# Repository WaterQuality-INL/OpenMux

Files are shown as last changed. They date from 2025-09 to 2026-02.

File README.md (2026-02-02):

# OpenMux Overview
OpenMux is an extension of the research conducted within the framework of the [OPTIRAS project](https://www.optiras.org/), particularly from the [Water Quality Group](https://inl.int/espina-research-group/) at the [International Iberian Nanotechnology Laboratory](https://inl.int/).
We aim to provide an open-source multiplexer adaptor for the [EmStat4 LR/HR potentiostat](https://www.palmsens.com/product/emstat4m/) by combining hardware design with software integration. This innovation enhances experimental efficiency and scalability for researchers and engineers at an exceptionally low cost, paving the way for applications such as multiplexed electrochemical sensing, automated assay platforms, and integrated IoT-based field monitoring systems for environmental, biomedical, or industrial electrochemical analysis.

The use of OpenMux is demonstrated in the article ["Multiplexed potentiometric sensing of nitrite in environmental waters"](https://doi.org/10.1016/j.aca.2026.345190) [1].

---

## About

This repository provides **OpenMux**, a homemade and cost-effective multiplexer adaptor for the EmStat4 OEM module from Palmsens. 
The adaptor is integrated with the potentiostat using the [**MethodScript**]([https://github.com/PalmSens](https://www.palmsens.com/methodscript/)) protocol provided by the manufacturer.

The system consists of two main modules:  

1. **Hardware Module** – the multiplexer adaptor (figure 1), whose schematics and PCB layout were developed using KiCad 7.0. Schematic, layout, and Gerber files can be found in the `Hardware/` folder (see [schematic.pdf](Hardware/schematic.pdf) and [layout.pdf](Hardware/layout.pdf) for pictures).  
2. **Graphical User Interface (GUI)** – a graphical user interface (figure 2) to control the adaptor, implemented in Python 3.8. The GUI is located in the `Application/`  folder.

<div align="center">
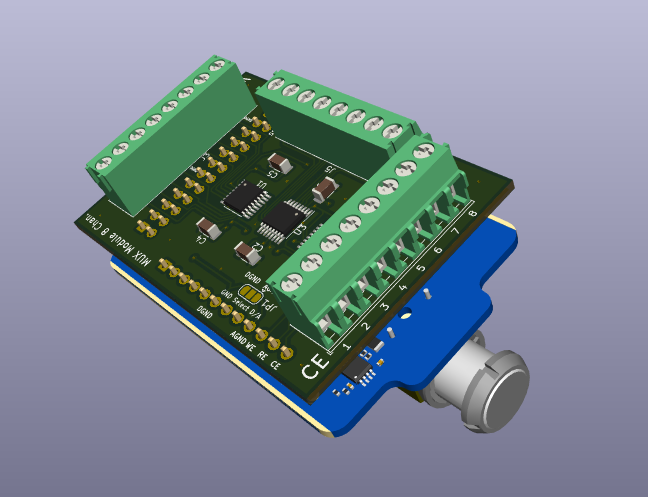
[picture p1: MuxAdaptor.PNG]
Multiplexer Adaptor for EmStat4
  
  <p><em>Figure 1: OpenMux adaptor for EmStat4</em></p>
</div>

<div align="center">
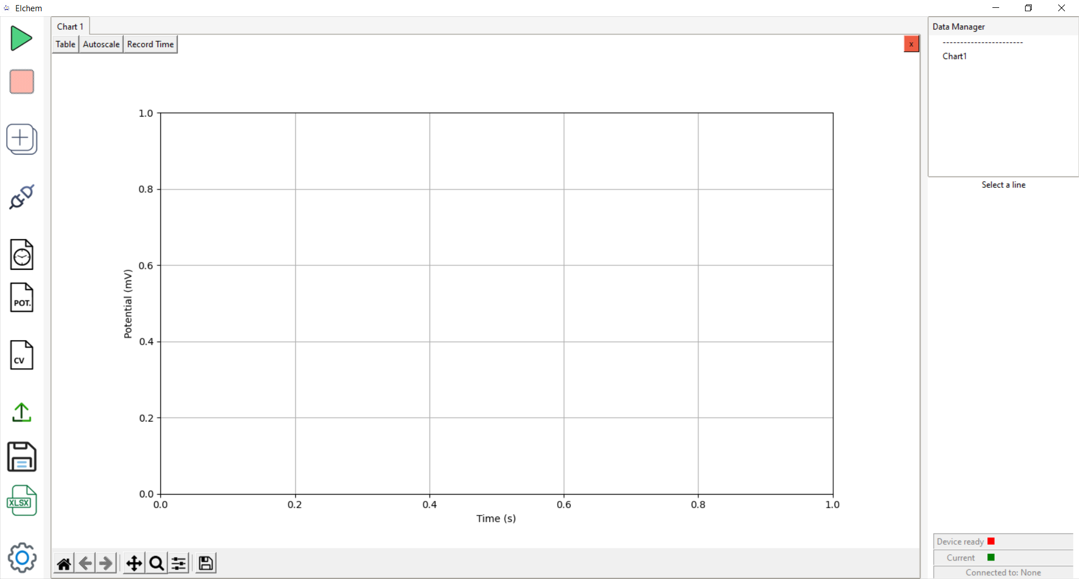
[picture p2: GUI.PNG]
Graphical User Interface
  
  <p><em>Figure 2: OpenMux GUI</em></p>
</div>

The application of OpenMux for electrochemical methods is described in the scientific literature [2].

## Who is this for?

- Electrochemists who want a cheap and modular, open platform for integrating sensors and data backends for:
   - Environmental or industrial monitoring applications
   - Scaling up sensor optimisation and/or preparation in the lab
  
---

## Costs

The approximate cost of the electronic components (excluding the PCB) is around **€40**. Key components include:

| Quantity | Component | Price | Link |
|---|---|---|---|
| 3x | ADG1408YRUZ Multiplexer | €10 | [Digi-Key](https://www.digikey.pt/en/products/detail/analog-devices-inc/ADG1408YRUZ/1206709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) |
| 3x | Phoenix Terminal Block 8-pos | €1.60 | [Digi-Key](https://www.digikey.pt/en/products/detail/phoenix-contact/1984675/950853) |
| 3x | Male Pin Header 12-pos | €0.14 | [Digi-Key](https://www.digikey.pt/en/products/detail/adam-tech/PH1-12-UA/9830395) |
| 3x | Female Pin Header 12-pos | €0.49 | [Digi-Key](https://www.digikey.pt/en/products/detail/w%C3%BCrth-elektronik/61301211821/16608531) |

---

## Getting Started

1) Clone or download the repository 
```bash
git clone https://github.com/WaterQuality-INL/OpenMux.git
cd OpenMux
```

2) Hardware and production
- Gerber files for production: `Hardware/production/Mux_Module.zip`
- Schematics and PCB: in `Hardware/` (KiCad 7.x)
- Fabricate the PCB (JLCPCB, PCBWay, etc.), order components, and assemble.

3) Software requirements
- Python 3.8 or newer (3.8–3.11 recommended)
- OS: Windows, Linux, or macOS (GUI tested on Windows; Linux/macOS supported)
- The Application uses `MethodScript-firmware/` and `Icons/` folders; these must be present when running the packaged executable (see Packaging below).

4) Run the GUI (development)

Windows (cmd / PowerShell)
```bash
cd Application
python -m venv venv
venv\Scripts\activate.bat    # PowerShell: venv\Scripts\Activate.ps1
pip install -r requirements.txt
python EL_MUX.py
```

Linux / macOS
```bash
cd Application
python3 -m venv venv
source venv/bin/activate
pip install -r requirements.txt
python3 EL_MUX.py
```

5) OPTIONAL: Packaging (creating an executable)

Alternatively, an executable file can also be created, allowing this application to run in computers where python is not installed.
```bash
cd Application
venv\Scripts\activate.bat
pyinstaller -w -p "venv\Lib\site-packages" -i Icons/group-30_116053.ico --onefile EL_MUX.py
```

Notes:
- The produced executable still depends on the folders `MethodScript-firmware/` and `Icons/`. Place `EL_MUX.exe` into `Application/` alongside those folders before running.
- After verifying the executable works, you can remove the `build/` and `dist/` directories.

---

## Troubleshooting

- If the GUI cannot find the EmStat4 device, verify the USB/serial connection and port name.
- Ensure the virtual environment is activated and dependencies installed.
- For packaging issues, build the executable on the target OS (pyinstaller builds are OS-specific).

---

## License

- Software (Application/) is licensed under the MIT License.  
- <p> Hardware (Hardware/) is licensed under <a href=https://creativecommons.org/licenses/by/4.0/> CC BY 4.0 </a>    </p>

---

## Contributors
- Samuel Silva*

Supervision:
- Álvaro Geraldes**

Contacts:
- Samuel Silva, samuel.silva@inl.int
- Álvaro Geraldes, alvaro.geraldes@inl.int

*Water Quality Group, **Systems Engineering Group, International Iberian Nanotechnology Laboratory (INL)

---

## Acknowledgement
To PalmSens for MethodScript

This work is an extension of the research project funded by EEA (European Economic Area) Grants Portugal through the funded project PT-INN-0076—OPTIRAS.

---

## References
[1] Renato L. Gil, Samuel Silva, Marília B. Santos, Álvaro Geraldes, Begoña Espiña, Raquel B. Queirós. Multiplexed potentiometric sensing of nitrite in environmental waters. Analytica Chimica Acta 2026, https://doi.org/10.1016/j.aca.2026.345190

[2] Olesia Dudik, Renato L. Gil, Raquel B. Queirós. Critical assessment of different ion-to-electron transducers in modified screen-printed electrodes for potentiometric lithium sensing. Microchemical Journal 2025, 215, 114195, https://doi.org/10.1016/j.microc.2025.114195

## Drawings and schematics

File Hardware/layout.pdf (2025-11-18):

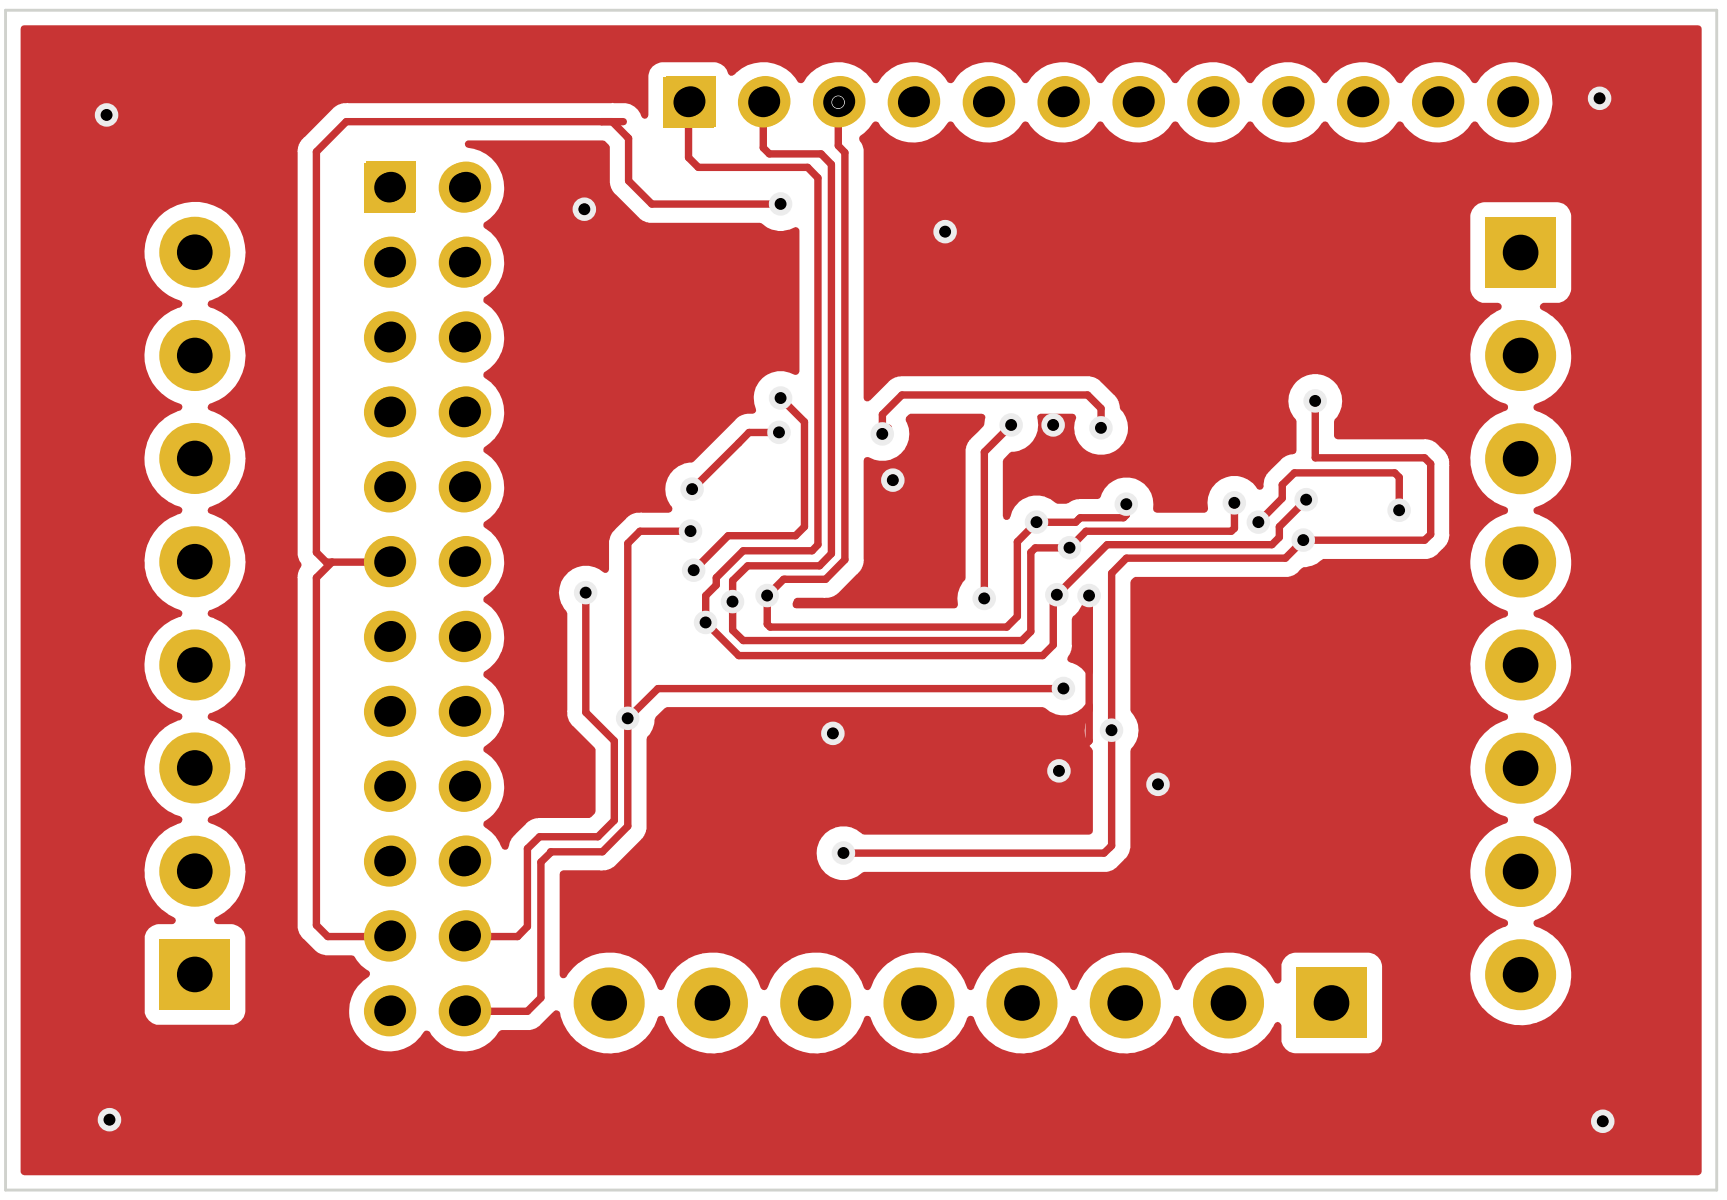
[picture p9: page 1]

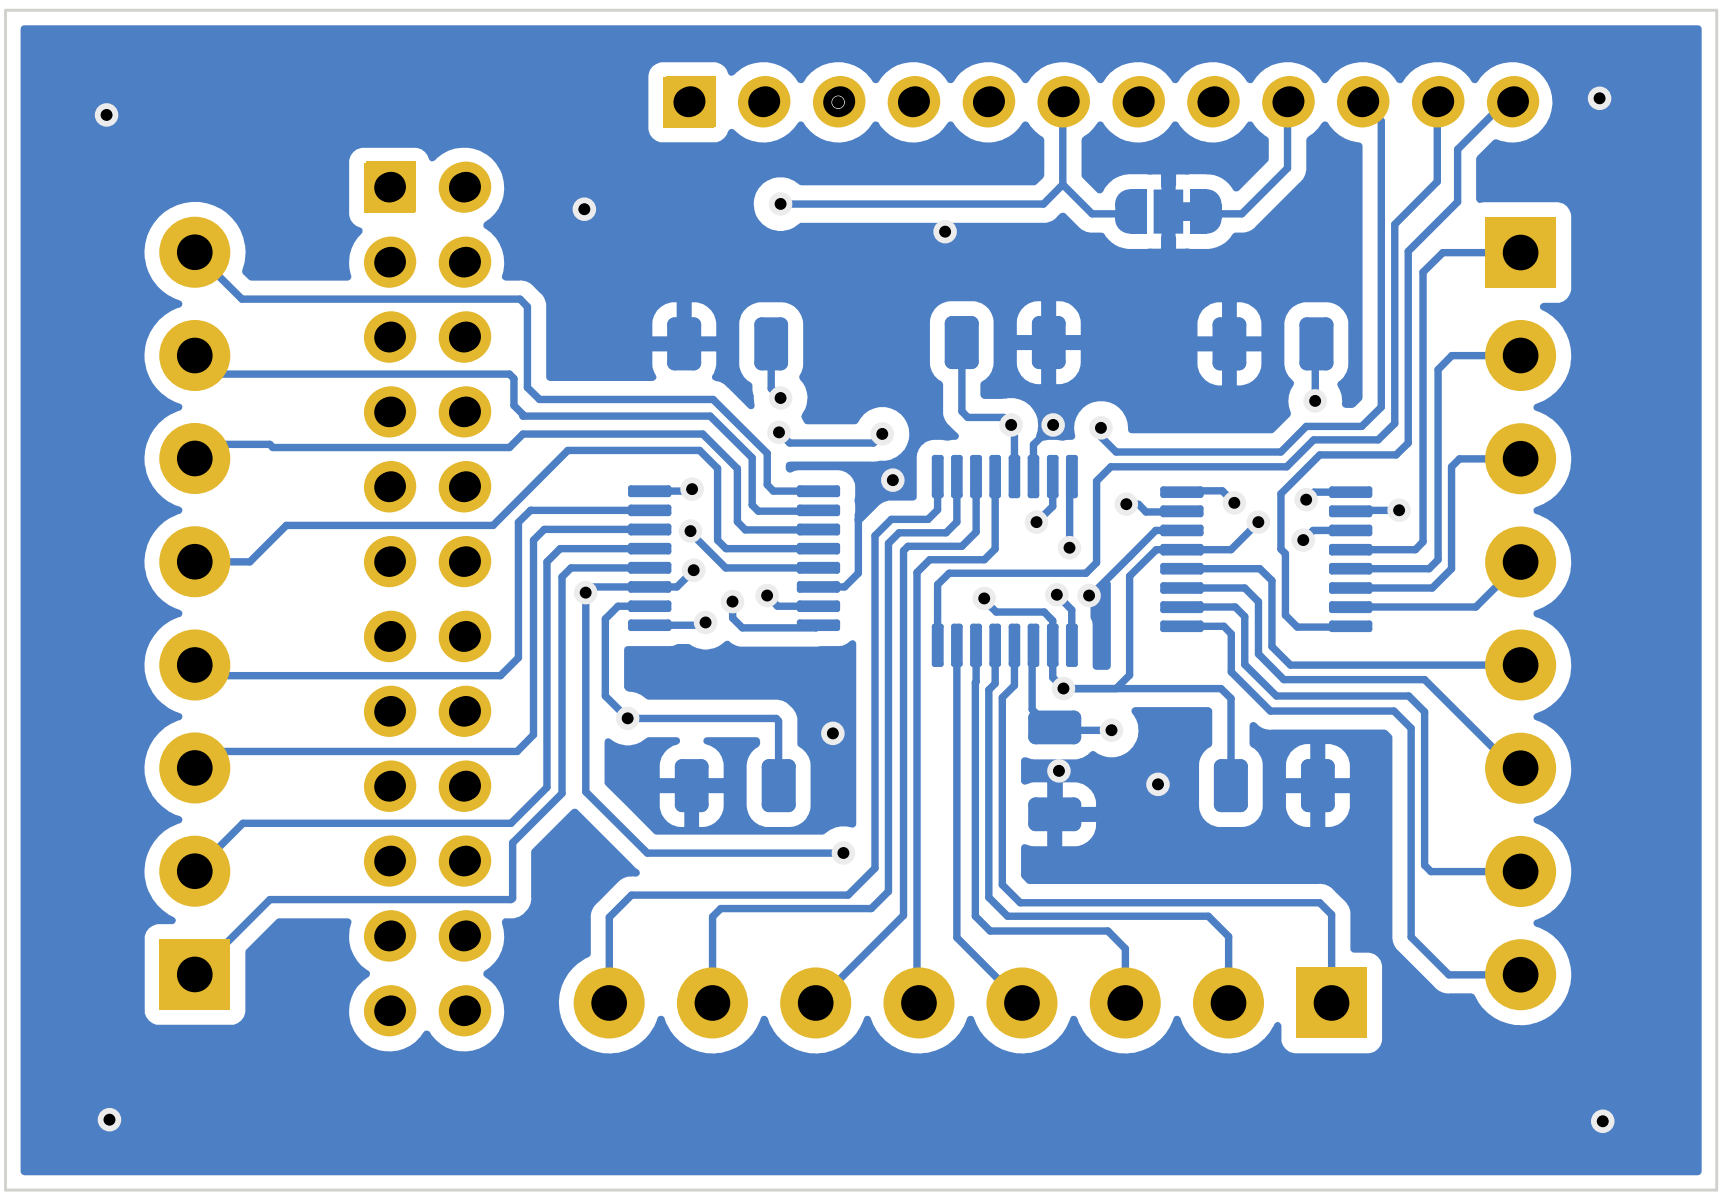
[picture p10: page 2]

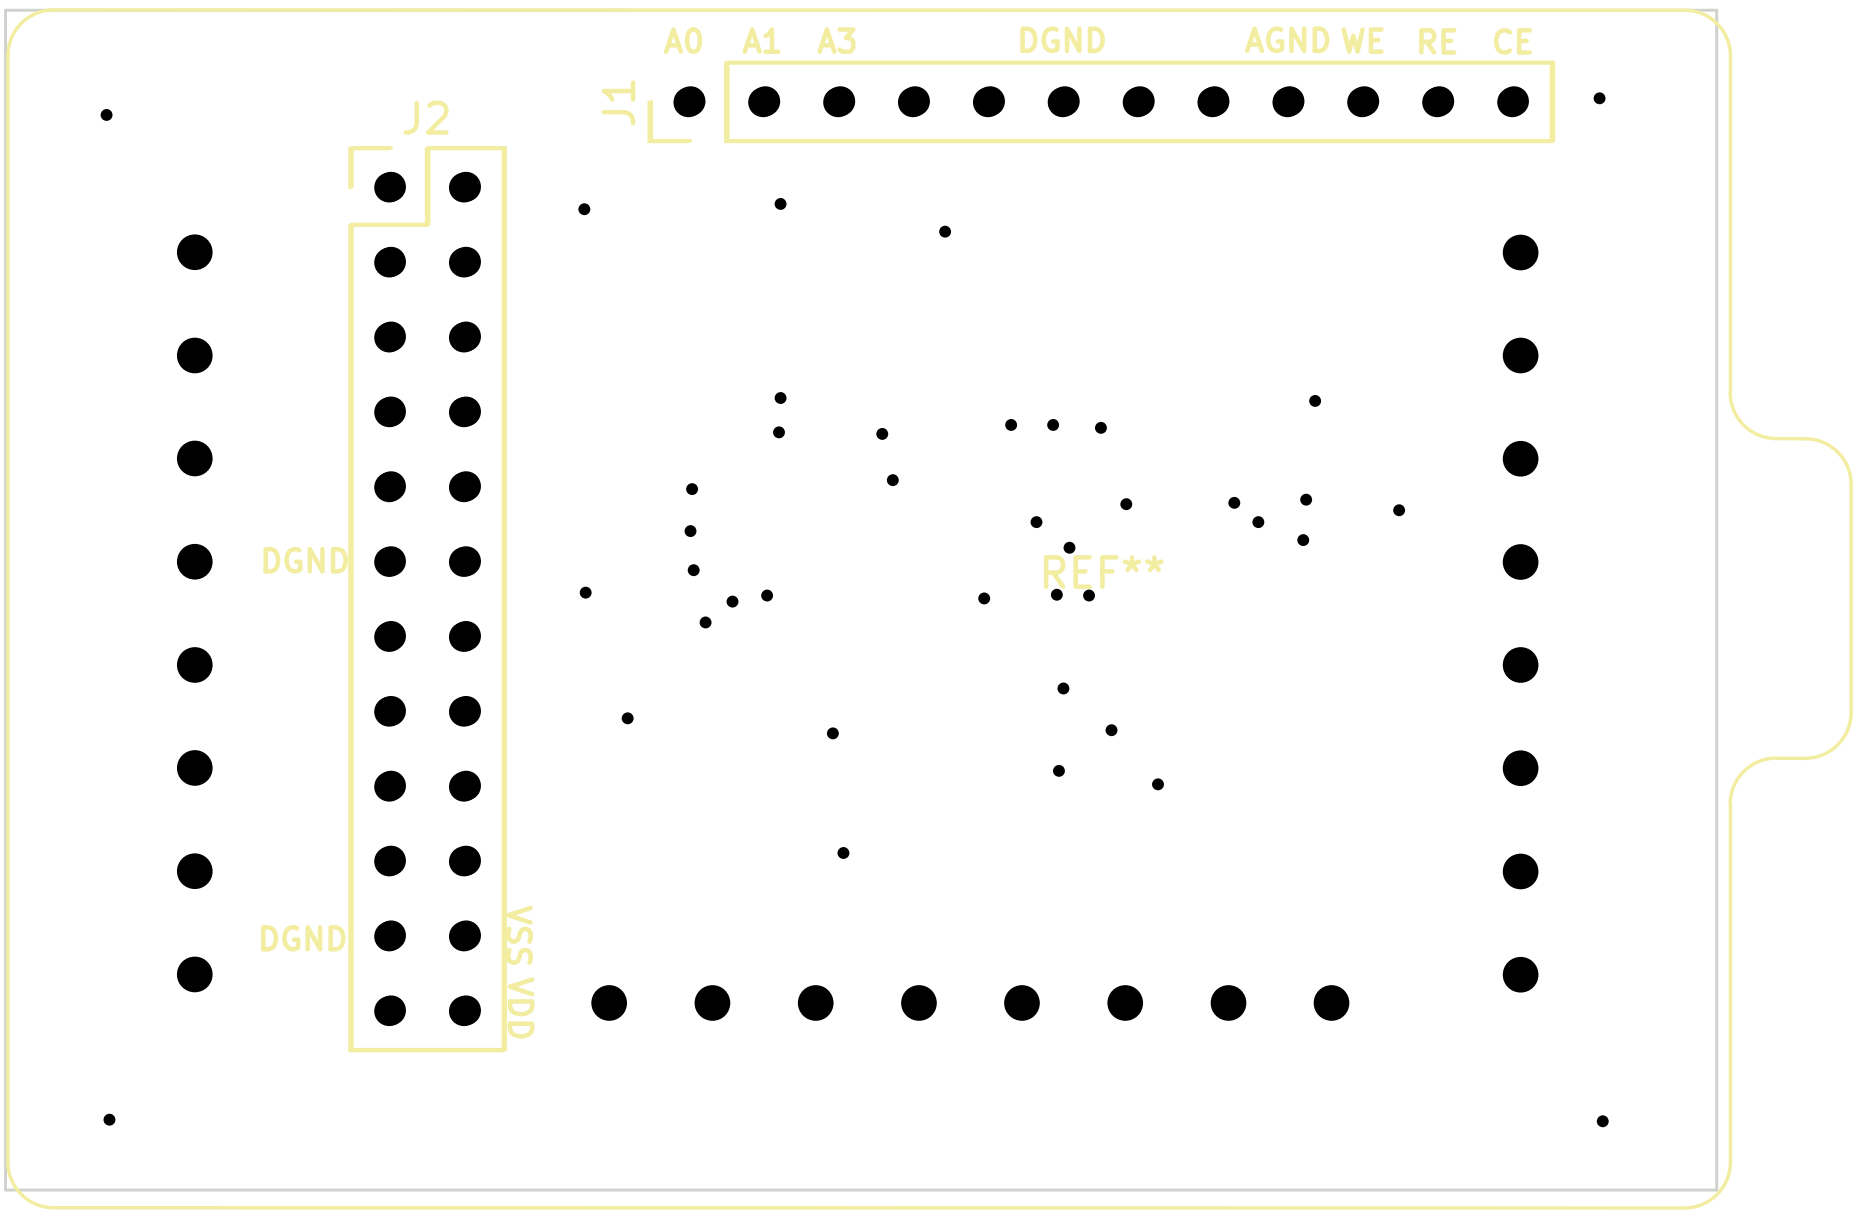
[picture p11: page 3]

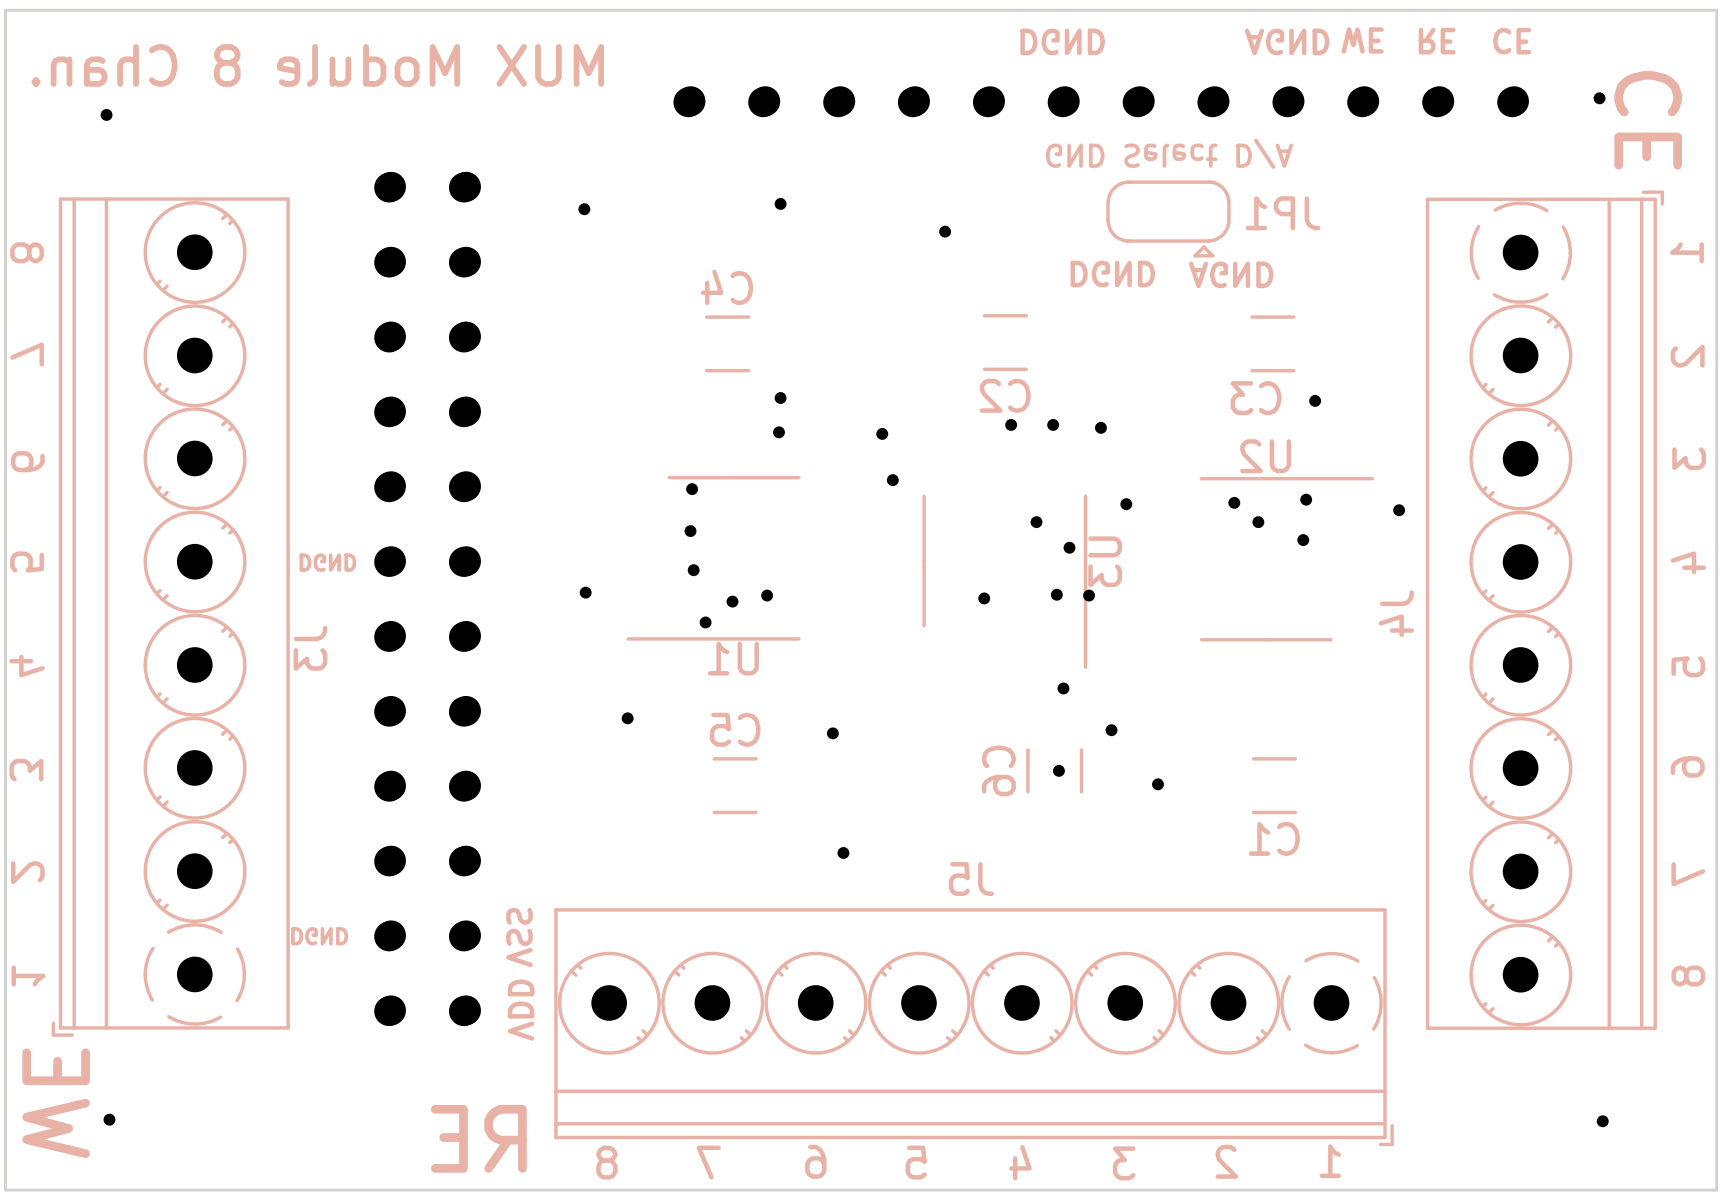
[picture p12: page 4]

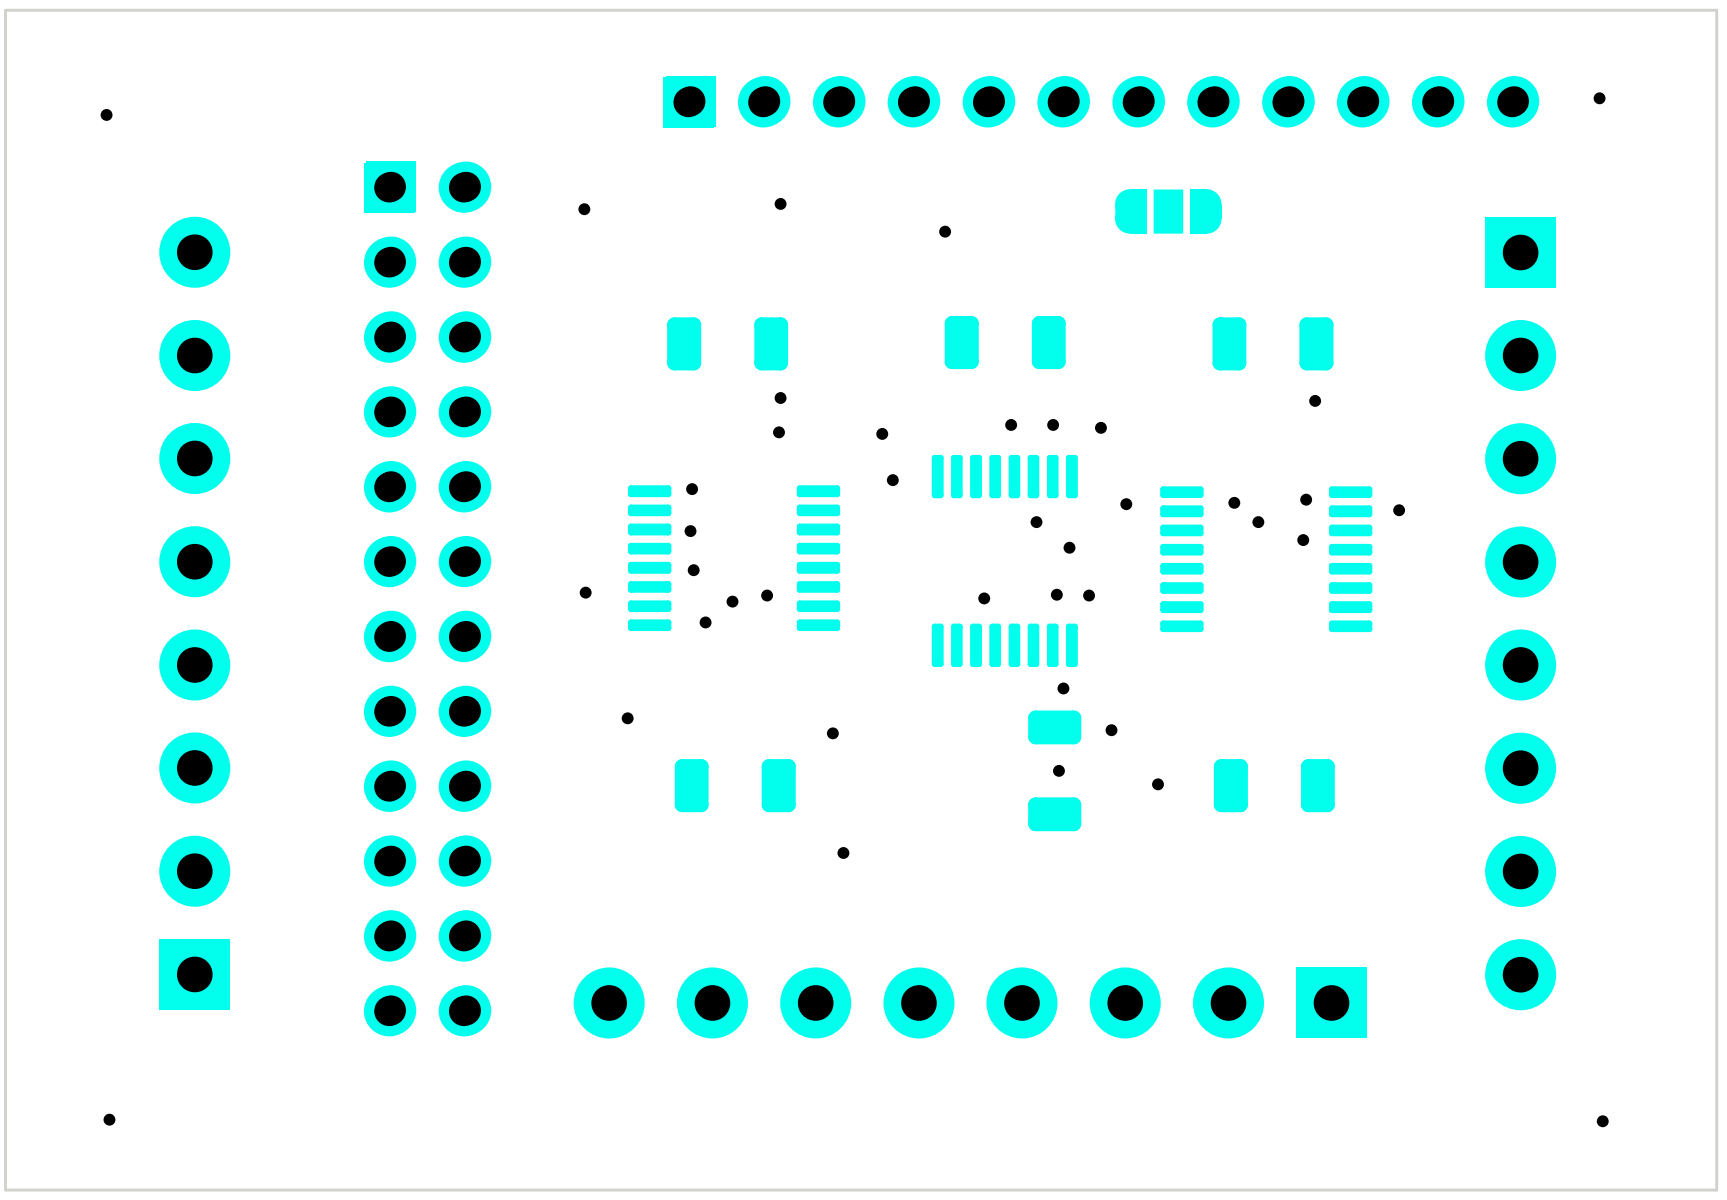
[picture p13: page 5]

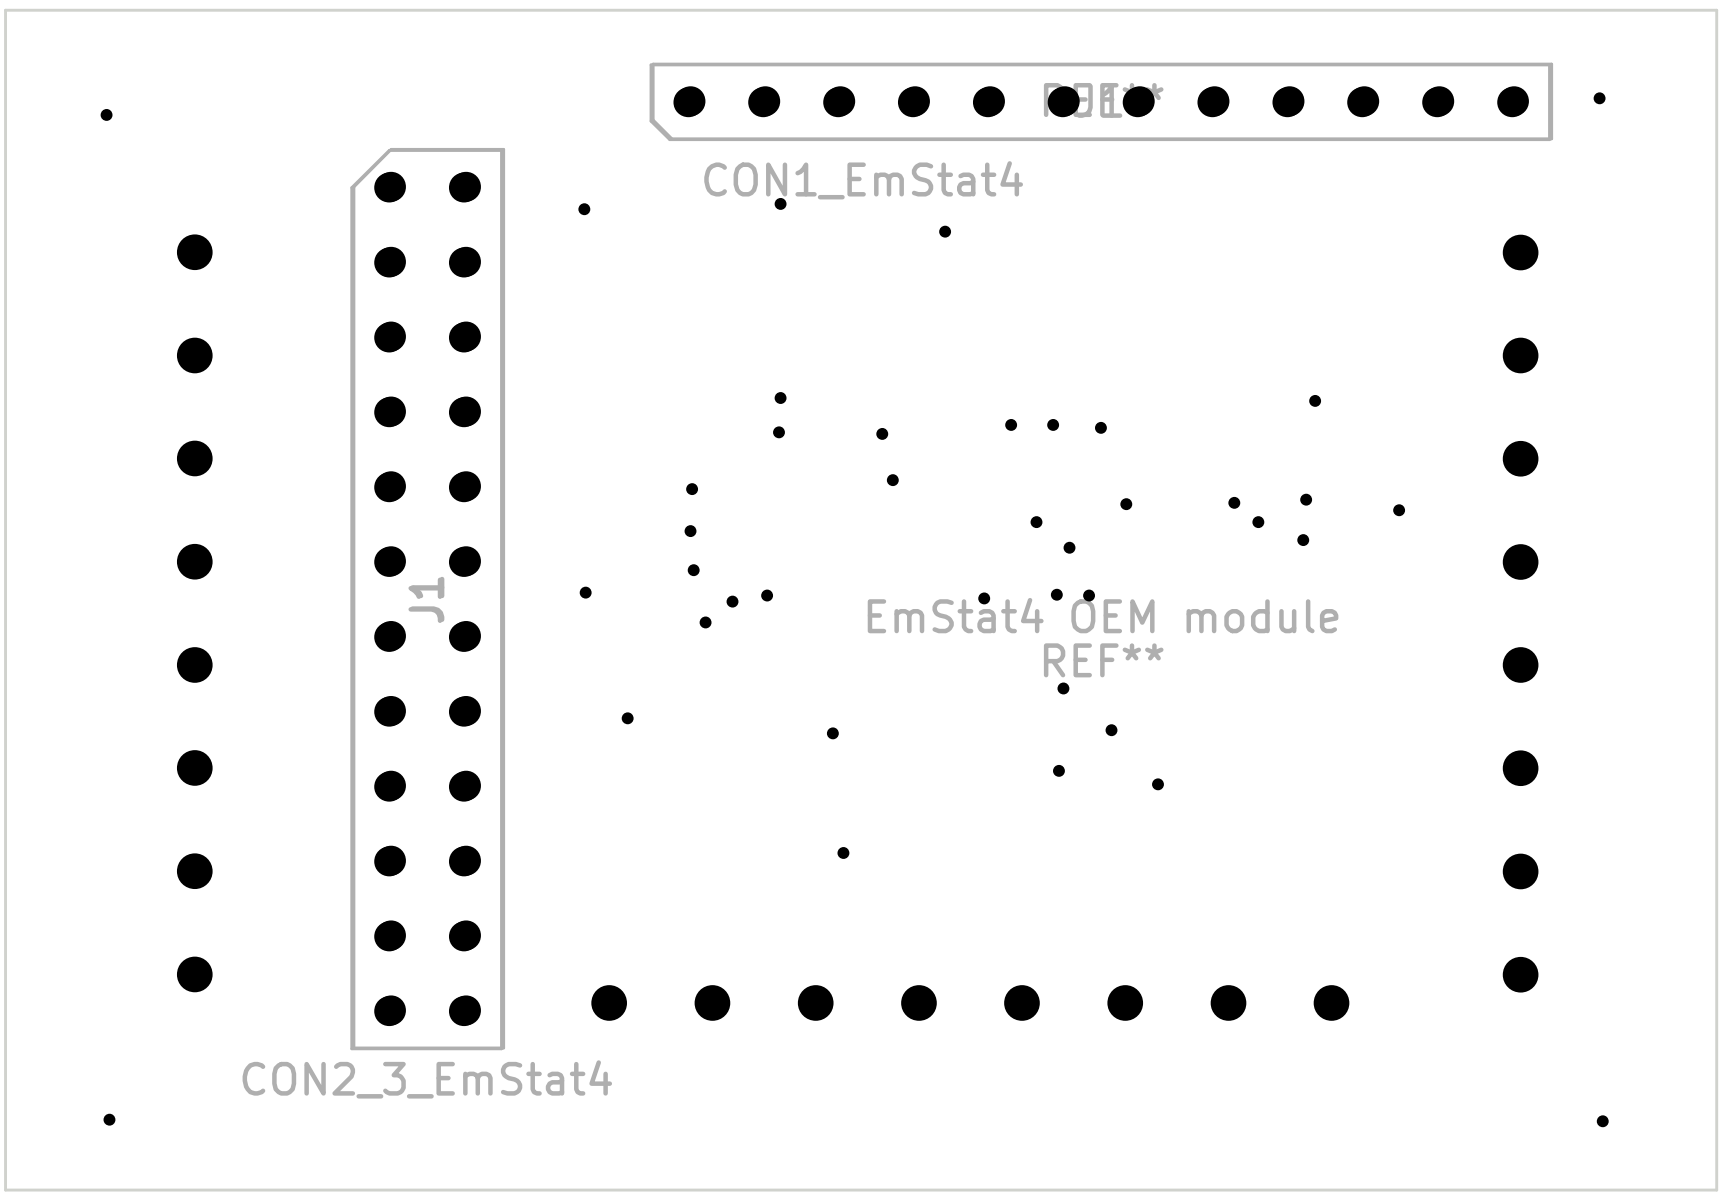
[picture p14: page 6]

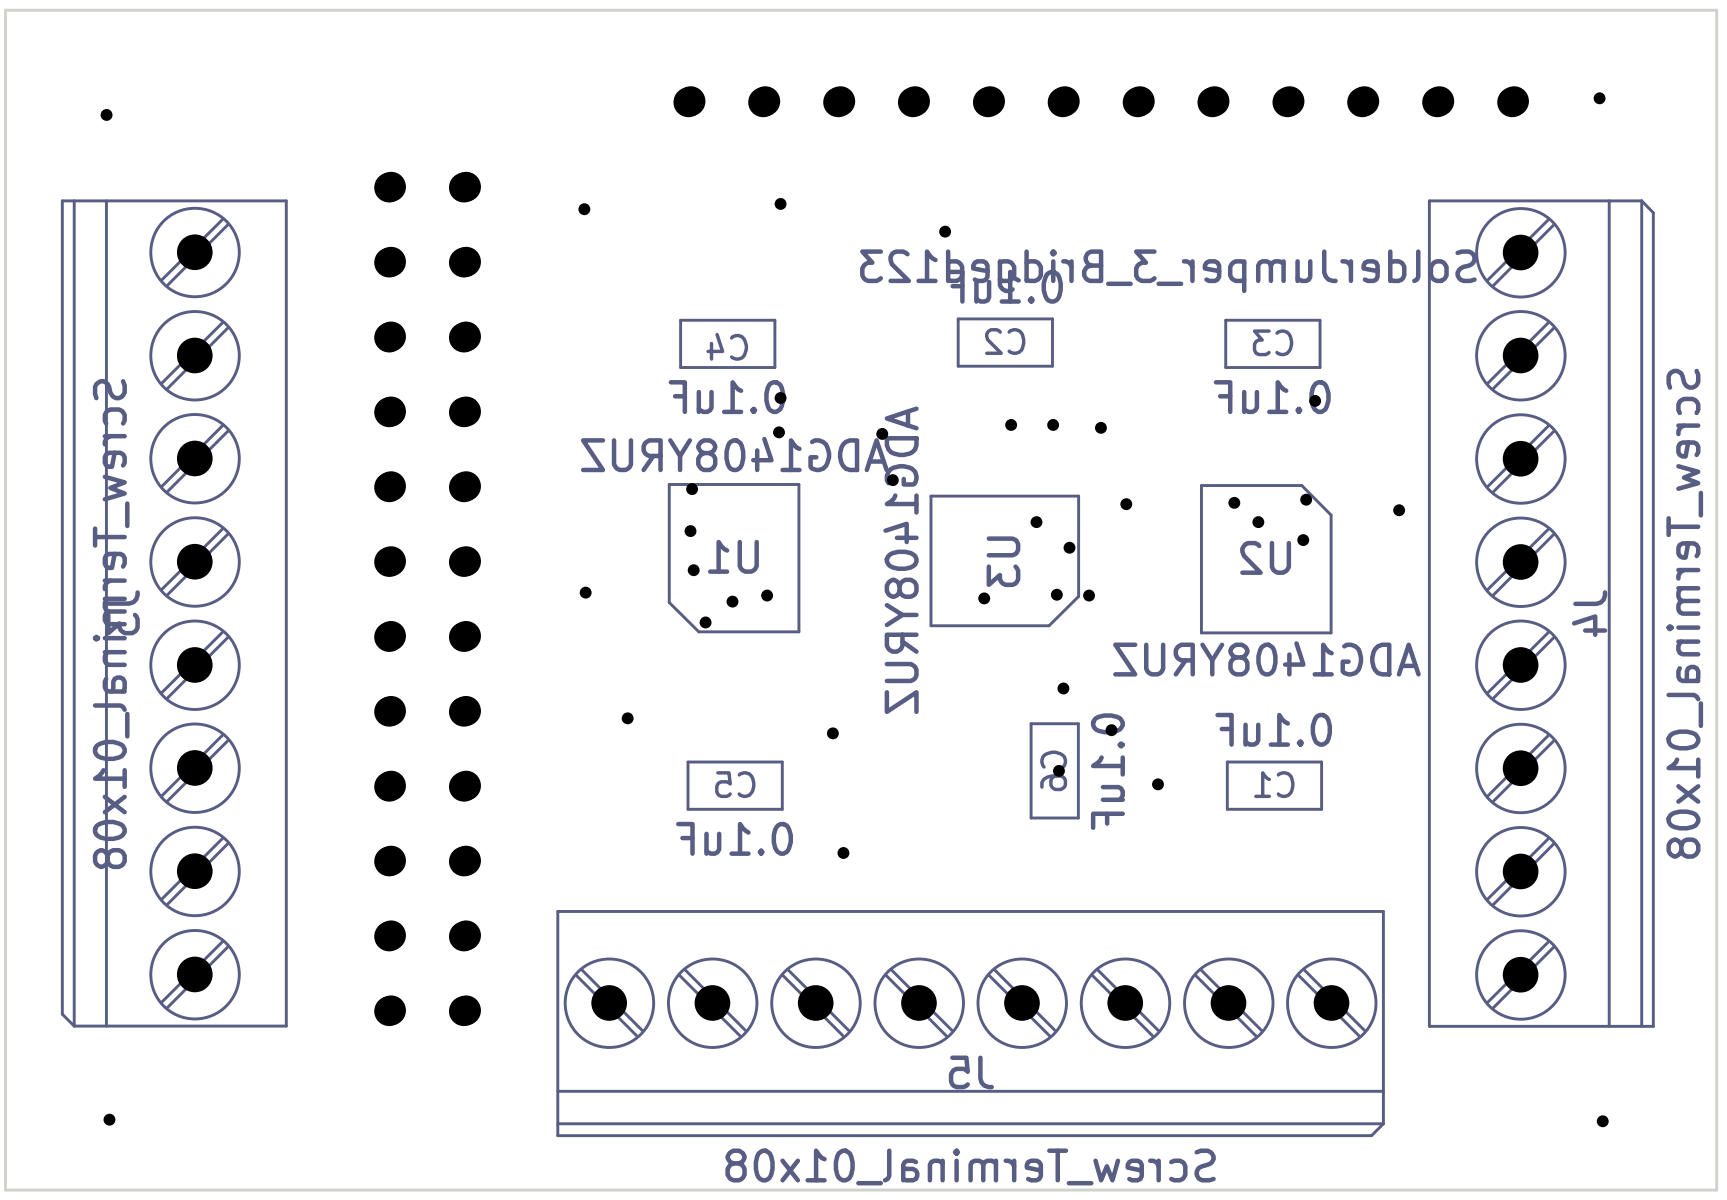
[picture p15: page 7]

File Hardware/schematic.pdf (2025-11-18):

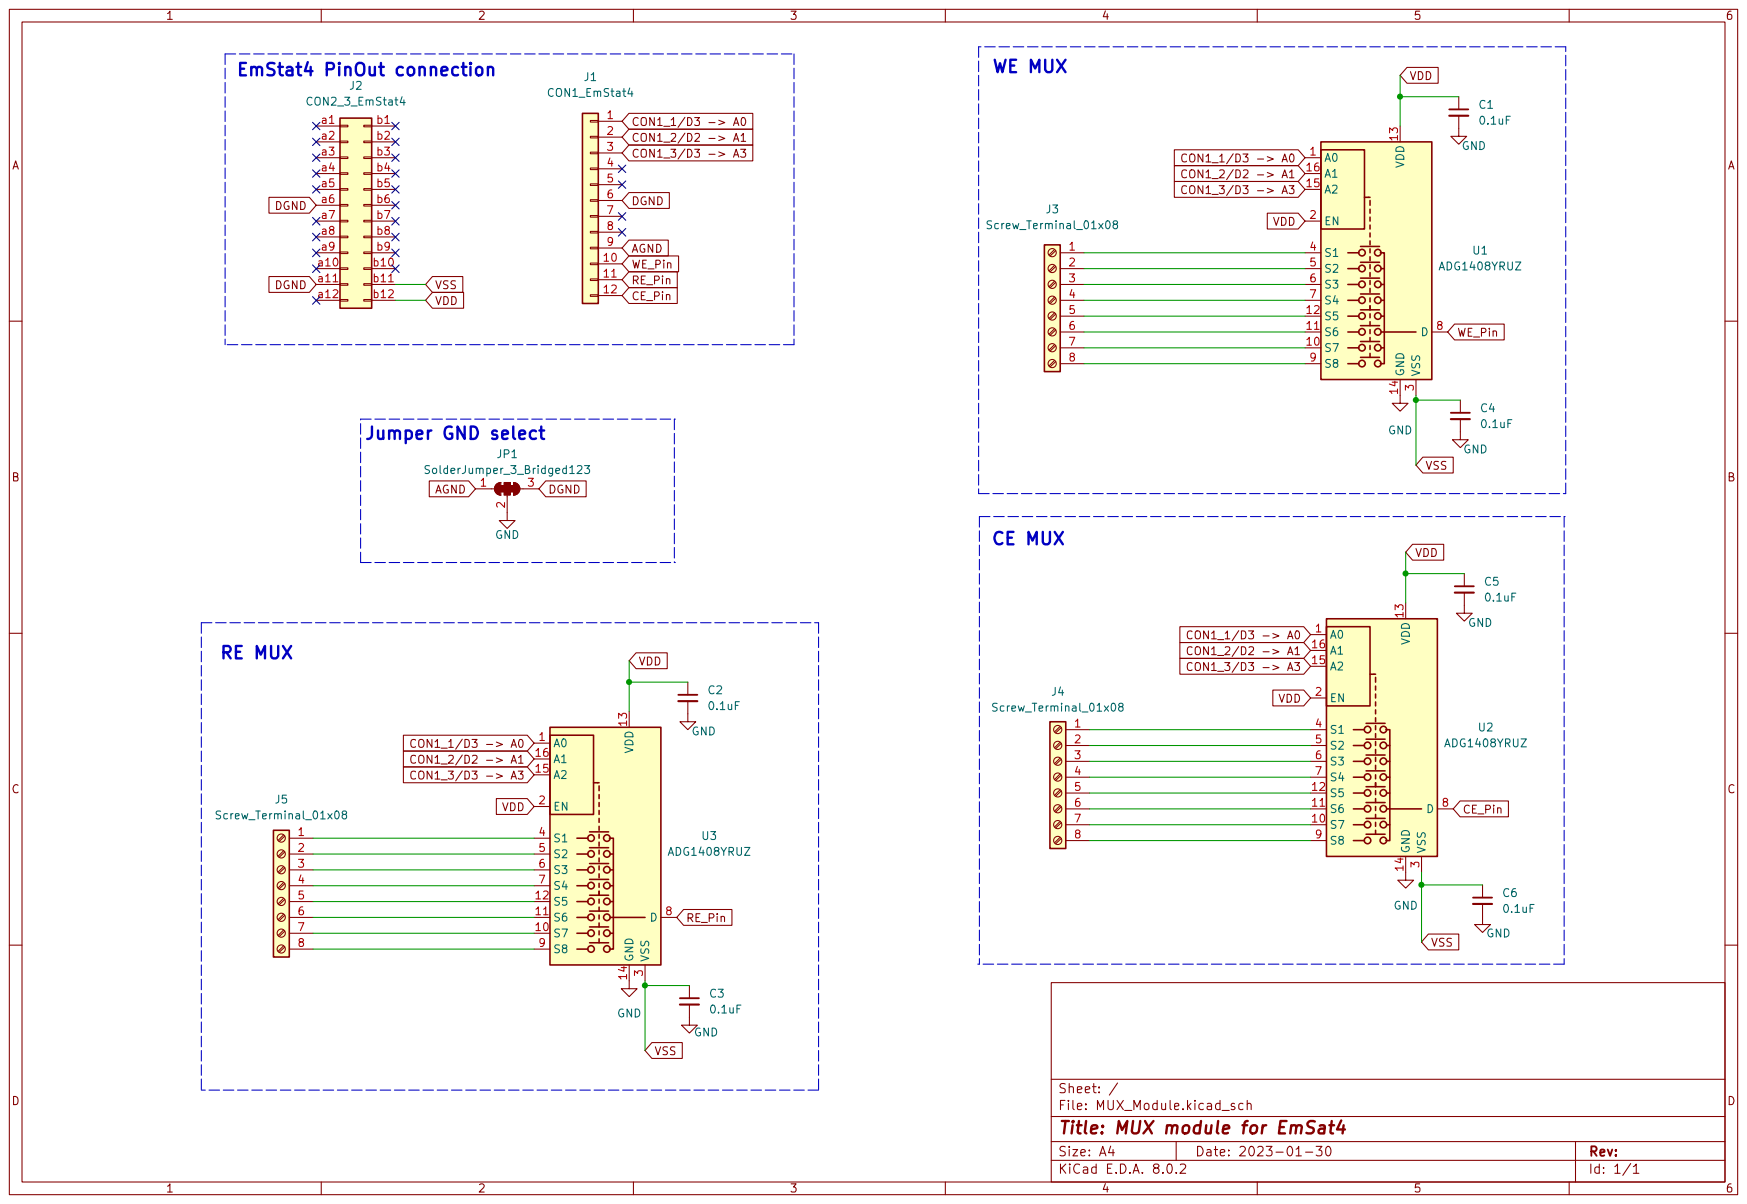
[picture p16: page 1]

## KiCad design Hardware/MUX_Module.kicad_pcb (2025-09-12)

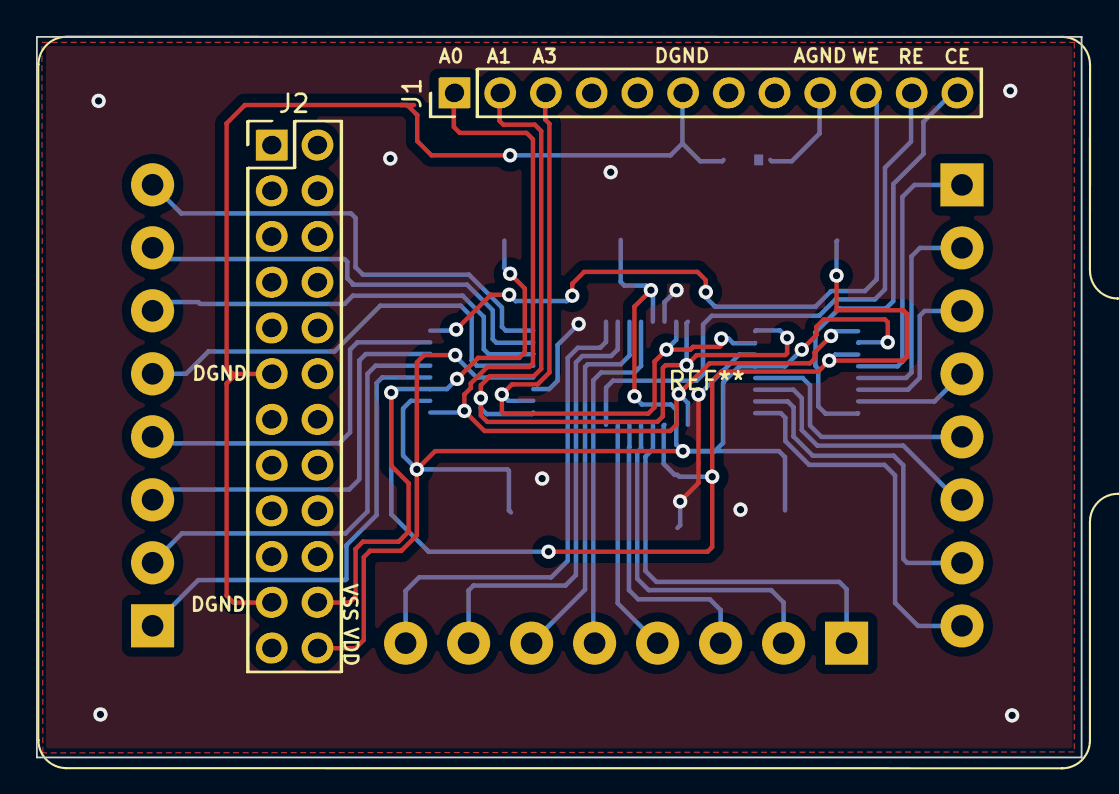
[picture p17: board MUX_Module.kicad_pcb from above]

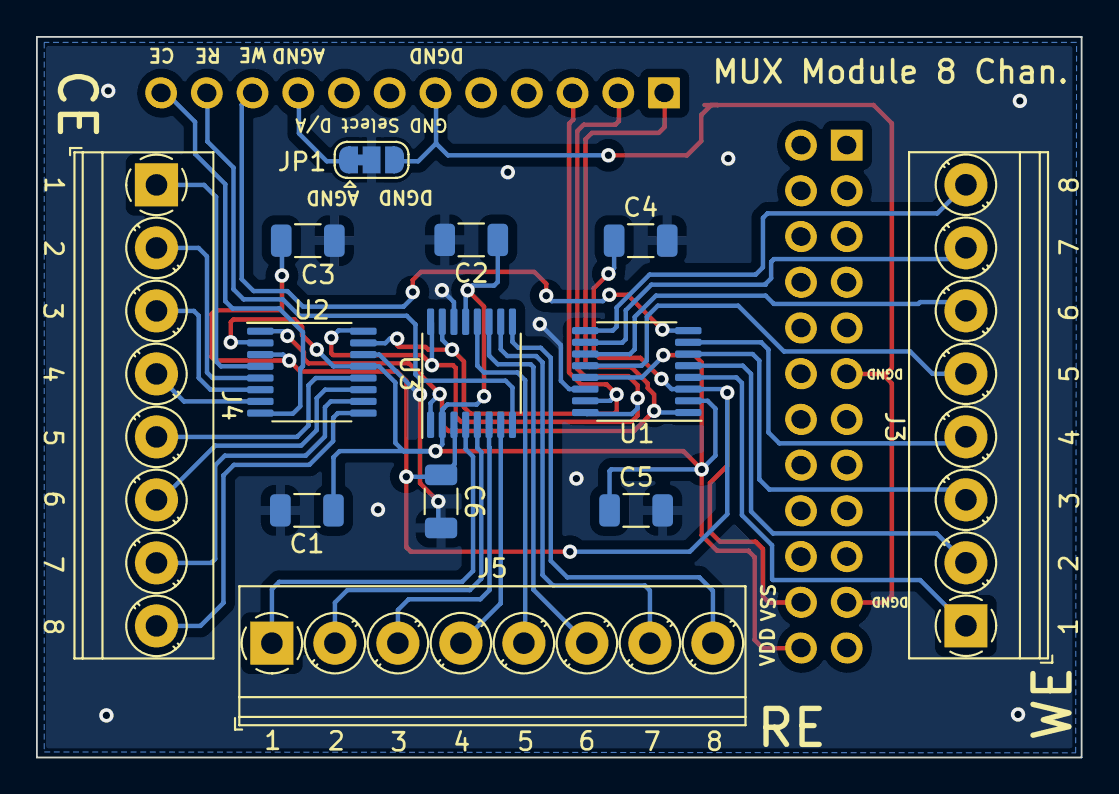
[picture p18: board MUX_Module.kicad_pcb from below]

Board: 2 copper layers, 58.0 x 40.0 mm, 15 parts (13 on the bottom side), 35 nets.

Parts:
C1, C2, C3, C4, C5, C6: 0.1uF; C_1206_3216Metric
J1: CON1_EmStat4; PinHeader_1x12_P2.54mm_Vertical
J2: CON2_3_EmStat4; PinHeader_2x12_P2.54mm_Vertical
J3, J4, J5: Screw_Terminal_01x08; TerminalBlock_Phoenix_PT-1,5-8-3.5-H_1x08_P3.50mm_Horizontal
JP1: SolderJumper_3_Bridged123; SolderJumper-3_P1.3mm_Bridged12_RoundedPad1.0x1.5mm
U1, U2, U3: ADG1408YRUZ; TSSOP-16_4.4x5mm_P0.65mm

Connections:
AGND: J1.9, JP1.1 (A)
CE_Pin: J1.12, U2.8 (D)
CON1_1/D3 -> A0: J1.1, U1.1 (A0), U2.1 (A0), U3.1 (A0)
CON1_2/D2 -> A1: J1.2, U1.16 (A1), U2.16 (A1), U3.16 (A1)
CON1_3/D3 -> A3: J1.3, U1.15 (A2), U2.15 (A2), U3.15 (A2)
DGND: J1.6, JP1.3 (B)
GND: C1.2, C2.2, C3.2, C4.2, C5.2, C6.2, JP1.2 (C), U1.14 (GND), U2.14 (GND), U3.14 (GND)
unnamed: J3.1, U1.4 (S1)
unnamed: J3.2, U1.5 (S2)
unnamed: J3.3, U1.6 (S3)
unnamed: J3.4, U1.7 (S4)
unnamed: J3.5, U1.12 (S5)
unnamed: J3.6, U1.11 (S6)
unnamed: J3.7, U1.10 (S7)
unnamed: J3.8, U1.9 (S8)
unnamed: J4.1, U2.4 (S1)
unnamed: J4.2, U2.5 (S2)
unnamed: J4.3, U2.6 (S3)
unnamed: J4.4, U2.7 (S4)
unnamed: J4.5, U2.12 (S5)
unnamed: J4.6, U2.11 (S6)
unnamed: J4.7, U2.10 (S7)
unnamed: J4.8, U2.9 (S8)
unnamed: J5.1, U3.4 (S1)
unnamed: J5.2, U3.5 (S2)
unnamed: J5.3, U3.6 (S3)
unnamed: J5.4, U3.7 (S4)
unnamed: J5.5, U3.12 (S5)
unnamed: J5.6, U3.11 (S6)
unnamed: J5.7, U3.10 (S7)
unnamed: J5.8, U3.9 (S8)
RE_Pin: J1.11, U3.8 (D)
VDD: C1.1, C2.1, C5.1, U1.2 (EN), U1.13 (VDD), U2.2 (EN), U2.13 (VDD), U3.2 (EN), U3.13 (VDD)
VSS: C3.1, C4.1, C6.1, U1.3 (VSS), U2.3 (VSS), U3.3 (VSS)
WE_Pin: J1.10, U1.8 (D)

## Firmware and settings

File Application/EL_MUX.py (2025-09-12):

import json

from tkinter import messagebox
from tkinter import filedialog

from costume_widgets import *


import serialcom


import threading
import pandas as pd
from tools.export2xl_tool import export_window


""" For OEM system and multiplexing module"""
from device import Emstat4
from ScriptEditor import MSEditor, MSEditorCrono
from CV_MUX_Editor import MSEditorCV



def connection():
    # Creates the window that opens when option connection is selected from the menu
    def refresh_listbox():
        # Identifies the available ports for communication
        port_list = serialcom.see_ports()
        my_listbox.delete(0, END)
        for i in range(0, len(port_list)):
            my_listbox.insert(0, port_list[i])

    def connect_port(e=None):
        # establishes the connection to the selected port
        port_name = my_listbox.get(ANCHOR)
        port_name = port_name.split(' ')
        portID = port_name[0]

        global channel, EMS4  # variable that tracks current connected port
        # channel = serialcom.connect_to(portID, int(bauds.get()))
        # global ser
        # ser = serial.Serial(portID, baudrate=int(bauds.get()), parity=serial.PARITY_ODD, timeout=1)
        channel = portID

        EMS4 = Emstat4(channel, timeout=5)

        if channel != "None":
            # if connection is established successfully to the desired port
            main_status.config(text="Connected to: " + portID)
            device_LED.set_led_status(True)
            close_top()
            # serialcom.read_port(channel)
        else:
            # if connection is not established successfully to the desired port
            main_status.config(text="Connection failed")
            device_LED.set_led_status(False)

        if e is not None:
            close_top()

    def scroll_function(event):
        if event.delta > 0:
            my_listbox.xview_scroll(-1, "unit")
        else:
            my_listbox.xview_scroll(1, "unit")

    def close_top():
        my_listbox.unbind_all('<MouseWheel>')
        top.grab_release()
        top.destroy()

    top = Toplevel()
    # top.attributes('-topmost', 'true')
    # top.geometry("400x400")
    top.resizable(False, False)
    top.transient(root)
    top.lift()
    top.protocol("WM_DELETE_WINDOW", close_top)
    top.grab_set()

    # creates the input for the bauds number
    f_properties = LabelFrame(top, text="Connection properties")
    f_properties.pack()
    l_bauds = Label(f_properties, text="Bauds")
    bauds = Entry(f_properties, fg="grey")
    bauds.insert(0, str(153600))
    l_bauds.grid(row=0, column=0)
    bauds.grid(row=0, column=1)

    # Create interactive display port window
    my_frame = LabelFrame(top, text="Ports")
    my_frame.pack()

    my_scrollbarX = Scrollbar(my_frame, orient=HORIZONTAL)
    my_scrollbarY = Scrollbar(my_frame, orient=VERTICAL)
    my_listbox = Listbox(my_frame, height=4, xscrollcommand=my_scrollbarX.set, yscrollcommand=my_scrollbarY.set)
    my_scrollbarY.config(command=my_listbox.yview)
    my_scrollbarX.config(command=my_listbox.xview)
    my_scrollbarY.pack(side=RIGHT, fill=Y)
    my_scrollbarX.pack(side=BOTTOM, fill=X)
    my_listbox.pack(fill=BOTH, expand=1)

    my_listbox.bind_all('<MouseWheel>', scroll_function)
    my_listbox.bind('<Return>', connect_port)

    # creates the buttons for interaction
    b_connect = Button(top, text="Connect", command=connect_port, bg="Azure2")
    b_refresh = Button(top, text="Refresh", command=refresh_listbox, bg="Azure2")
    b_close = Button(top, text="Close", command=close_top, bg="Azure2")
    b_connect.pack(fill=BOTH)
    b_refresh.pack(fill=BOTH)
    b_close.pack(fill=BOTH)

    # automatically updates the list of available ports
    refresh_listbox()


def load_xldata(file):
    """
    Loads the data from a excel file.
    :param
    filename: str
        string with the path to the desired file
    :return:
    xx: ndarray
        array with the frequencies
    yy: complex ndarray
        impedance array
    """
    df = pd.read_excel(io=file)

    # Getting only values as numpy array
    array = df.values

    volt = array[:, 0]
    curr = array[:, 1]

    flag = 'Not available!'

    add_data(xx=volt.tolist(), yy=curr.tolist(), flag=flag, filename=file.split('/')[-1].replace('.xlsx', ''))


def load_txtdata(file):
    with open(file, 'r') as data:
        data = data.read()

        # Getting flag
    try:
        flag, data = data.split('-tear-')
    except ValueError:
        flag = 'Not available!'

    volt = []
    curr = []
    for item in data.split('\n'):
        try:
            values = item.split('\t')
            volt.append(float(values[0]))
            curr.append(float(values[1]))
        except ValueError:
            pass
        except IndexError:
            pass

    add_data(xx=volt, yy=curr, flag=flag, filename=file.split('/')[-1].replace('.txt', ''))


def load_elchem(file):
    with open(file, 'r') as data:
        jsonStr = data.read()
    pyDic = json.loads(jsonStr)

    nCharts = len(pyDic['Charts'])
    for chart in pyDic['Charts']:
        add_chart()
        for line in chart['Lines']:
            # add lines to chart
            volt = line['x']
            curr = line['y']
            flag = line['tech']
            name = line['Name']
            add_data(xx=volt, yy=curr, flag=flag, filename=name)


def load_from_file():
    """ loads data from a CSV or space delimited file """
    file = filedialog.askopenfilename()

    if file != '':
        if file.find('.txt') != -1:
            load_txtdata(file)
        elif file.find('.xlsx') != -1:
            load_xldata(file)
        elif file.find('.elchem') != -1:
            load_elchem(file)
        else:
            messagebox.showerror('File type not valid', 'Only .txt or .xlsx or .elchem files can'
                                                        ' be loaded!')


def add_data(xx, yy, flag, filename):
    # TODO is this try/except block really needed
    try:
        Active_tab = update_tabs()
        # Extracting graph (axes) from tab
        voltam_graph = Active_tab.chart

        # Creating series in graphs (axes)
        voltam_series = ttm.NewSeries(voltam_graph, flag)
        line = voltam_series.add_coordinate_list(xx, yy)
        my_tree_menu.add_line(line, chart=Active_tab.chart, name=filename)
    except UnboundLocalError:
        print('Selected file not valid for data reading')


def add_chart():
    global char_num
    # Creating new tab
    char_num += 1
    Active_tab = my_notebook.add_costume_tab(label=f'Chart {char_num}')
    # Loading widget view to second tab and defining the working chart
    Active_tab.update_tree(my_tree_menu)
    my_tree_menu.add_chart(Active_tab.chart, 'Chart' + str(char_num))
    # Lifting New tab
    my_notebook.select(Active_tab.tab)
    return Active_tab
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

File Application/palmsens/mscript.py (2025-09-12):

"""
PalmSens MethodSCRIPT module

This module provides functionality to translate and interpret the output_ni of a
MethodSCRIPT (the measurement data).

The most relevant functions are:
  - parse_mscript_data_package(line)
  - parse_result_lines(lines)

-------------------------------------------------------------------------------
Copyright (c) 2021 PalmSens BV
All rights reserved.

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
   - Redistributions of source code must retain the above copyright notice,
     this list of conditions and the following disclaimer.
   - Neither the name of PalmSens BV nor the names of its contributors
     may be used to endorse or promote products derived from this software
     without specific prior written permission.
   - This license does not release you from any requirement to obtain separate 
	  licenses from 3rd party patent holders to use this software.
   - Use of the software either in source or binary form must be connected to, 
	  run on or loaded to an PalmSens BV component.

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
# Standard library imports
import collections
import math
import warnings

# Third-party imports
import numpy as np


# Custom types
VarType = collections.namedtuple('VarType', ['id', 'name', 'unit'])
MScriptVar = collections.namedtuple('MScriptVar', ['type', 'value', 'value_string', 'metadata'])

# Dictionary for the conversion of the SI prefixes.
SI_PREFIX_FACTOR = {
    # supported SI prefixes:
    'a': 1e-18,  # atto
    'f': 1e-15,  # femto
    'p': 1e-12,  # pico
    'n': 1e-9,   # nano
    'u': 1e-6,   # micro
    'm': 1e-3,   # milli
    ' ': 1e0,
    'k': 1e3,    # kilo
    'M': 1e6,    # mega
    'G': 1e9,    # giga
    'T': 1e12,   # tera
    'P': 1e15,   # peta
    'E': 1e18,   # exa
    # special case:
    'i': 1e0,    # integer
}

# List of MethodSCRIPT variable types.
MSCRIPT_VAR_TYPES_LIST = [
    VarType('aa', 'unknown', ''),

    VarType('ab', 'WE vs RE potential', 'V'),
    VarType('ac', 'CE vs GND potential', 'V'),
    VarType('ad', 'SE vs GND potential', 'V'),
    VarType('ae', 'RE vs GND potential', 'V'),
    VarType('af', 'WE vs GND potential', 'V'),
    VarType('ag', 'WE vs CE potential', 'V'),

    VarType('as', 'AIN0 potential', 'V'),
    VarType('at', 'AIN1 potential', 'V'),
    VarType('au', 'AIN2 potential', 'V'),
    VarType('av', 'AIN3 potential', 'V'),
    VarType('aw', 'AIN4 potential', 'V'),
    VarType('ax', 'AIN5 potential', 'V'),
    VarType('ay', 'AIN6 potential', 'V'),
    VarType('az', 'AIN7 potential', 'V'),

    VarType('ba', 'WE current', 'A'),

    VarType('ca', 'Phase', 'degrees'),
    VarType('cb', 'Impedance', '\u2126'),  # NB: '\u2126' = ohm symbol
    VarType('cc', 'Z_real', '\u2126'),
    VarType('cd', 'Z_imag', '\u2126'),

    VarType('ce', 'EIS E TDD', 'V'),
    VarType('cf', 'EIS I TDD', 'A'),
    VarType('cg', 'EIS sampling frequency', 'Hz'),
    VarType('ch', 'EIS E AC', 'Vrms'),
    VarType('ci', 'EIS E DC', 'V'),
    VarType('cj', 'EIS I AC', 'Arms'),
    VarType('ck', 'EIS I DC', 'A'),

    VarType('da', 'Applied potential', 'V'),
    VarType('db', 'Applied current', 'A'),
    VarType('dc', 'Applied frequency', 'Hz'),
    VarType('dd', 'Applied AC amplitude', 'Vrms'),

    VarType('ea', 'Channel', ''),
    VarType('eb', 'Time', 's'),
    VarType('ec', 'Pin mask', ''),
    VarType('ed', 'Temperature', '\u00B0 Celsius'),  # NB: '\u00B0' = degrees symbol

    VarType('ha', 'Generic current 1', 'A'),
    VarType('hb', 'Generic current 2', 'A'),
    VarType('hc', 'Generic current 3', 'A'),
    VarType('hd', 'Generic current 4', 'A'),

    VarType('ia', 'Generic potential 1', 'V'),
    VarType('ib', 'Generic potential 2', 'V'),
    VarType('ic', 'Generic potential 3', 'V'),
    VarType('id', 'Generic potential 4', 'V'),

    VarType('ja', 'Misc. generic 1', ''),
    VarType('jb', 'Misc. generic 2', ''),
    VarType('jc', 'Misc. generic 3', ''),
    VarType('jd', 'Misc. generic 4', ''),
]

MSCRIPT_VAR_TYPES_DICT = {x.id: x for x in MSCRIPT_VAR_TYPES_LIST}

METADATA_STATUS_FLAGS = [
    (0x1, 'TIMING_ERROR'),
    (0x2, 'OVERLOAD'),
    (0x4, 'UNDERLOAD'),
    (0x8, 'OVERLOAD_WARNING'),
]

MSCRIPT_CURRENT_RANGES_EMSTAT_PICO = {
    0: '100 nA',
    1: '2 uA',
    2: '4 uA',
    3: '8 uA',
    4: '16 uA',
    5: '32 uA',
    6: '63 uA',
    7: '125 uA',
    8: '250 uA',
    9: '500 uA',
    10: '1 mA',
    11: '5 mA',
    128: '100 nA (High speed)',
    129: '1 uA (High speed)',
    130: '6 uA (High speed)',
    131: '13 uA (High speed)',
    132: '25 uA (High speed)',
    133: '50 uA (High speed)',
    134: '100 uA (High speed)',
    135: '200 uA (High speed)',
    136: '1 mA (High speed)',
    137: '5 mA (High speed)',
}

MSCRIPT_CURRENT_RANGES_EMSTAT4 = {
    # EmStat4 LR only:
    3: '1 nA',
    6: '10 nA',
    # EmStat4 LR/HR:
    9: '100 nA',
    12: '1 uA',
    15: '10 uA',
    18: '100 uA',
    21: '1 mA',
    24: '10 mA',
    # EmStat4 HR only:
    27: '100 mA',
}

MSCRIPT_POTENTIAL_RANGES_EMSTAT4 = {
    2:  "50 mV",
    3: "100 mV",
    4: "200 mV",
    5: "500 mV",
    6:   "1 V",
}


def get_variable_type(id):
    """Get the variable type with the specified id."""
    if id in MSCRIPT_VAR_TYPES_DICT:
        return MSCRIPT_VAR_TYPES_DICT[id]
    warnings.warn('Unsupported VarType id "%s"!' % id)
    return VarType(id, 'unknown', '')


def metadata_status_to_text(status):
    descriptions = []
    for mask, description in METADATA_STATUS_FLAGS:
        if status & mask:
            descriptions.append(description)
    if descriptions:
        return ' | '.join(descriptions)
    else:
        return 'OK'


def metadata_current_range_to_text(device_type, var_type, cr):
    cr_text = None
    if device_type == 'EmStat Pico':
        cr_text = MSCRIPT_CURRENT_RANGES_EMSTAT_PICO.get(cr)
    elif 'EmStat4' in device_type:
        # For EmStat4 series instruments, the range can be a current range or
        # potential range, depending on the variable type.
        if var_type.id in ['ab', 'cd']:
            cr_text = MSCRIPT_POTENTIAL_RANGES_EMSTAT4.get(cr)
        else:
            cr_text = MSCRIPT_CURRENT_RANGES_EMSTAT4.get(cr)
    return cr_text or 'UNKNOWN CURRENT RANGE'
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

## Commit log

2025-09-12 Adding hardware
    [MUX_Module.kicad_pcb, MUX_Module.kicad_sch]
2025-11-18 Adding pdf files with schematics and layout
2025-11-18 Clarify hardware module documentation in README
    Updated README to clarify file locations and add references to schematic and layout images.
2025-11-18 Fix links to schematic and layout PDFs in README
    Updated links in README for schematic and layout files.
